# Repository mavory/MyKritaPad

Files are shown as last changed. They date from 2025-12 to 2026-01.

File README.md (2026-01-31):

# MyKritaPad

MyKritaPad is a custom 9-key macropad powered by a Seeed Studio XIAO RP2040!
It includes 9 mechanical switches wired through 9 diodes and two EC11 rotary encoders for additional input control. ⭐



## Why did I do this?

I wanted to try something completely new that I had never done before. I was very interested in how everyone can create their own mini keyboard, so I tried it too.

## Notes

I started on Friday, October 28th. That day I saw that I could make my own mini keyboard, I registered and downloaded the programs. Then I opened KiCad and told myself that I would never do it (it was like flying a plane for the first time). Well, I had to overcome myself and started creating with it. At first it was terrible, but somehow I got over it.

Unfortunately, on October 29th I got sick and couldn't do anything at all, but on November 30th I overcame myself and started creating the first designs for my KritaPad. When I created it with it, I moved to Fusion, which I also looked into, what it was... Somehow I did it, even though I don't want to think about it.

Then on December 1st I overcame myself and spent the whole day at the computer to finish it. In the evening I finished and submitted the project.

## Features
- 9 mechanical keys  
- 9x diodes for proper key isolation  
- 12x SK6812 MINI-E addressable RGB LEDs (RGB LEDs unfortunately I had a bad footprint and because of that my neopixels don't work)  
- 2x EC11 rotary encoders
- Powered by Seeed Studio XIAO RP2040  
- Designed for use with KMK or custom firmware  

## PCB
The PCB is designed in KiCad and includes:
- 9 key switch footprints  
- diode matrix wiring  
- daisy-chained SK6812 MINI-E LEDs 
- pins for two rotary encoders  
- XIAO RP2040 as the main controller  

### Schematic

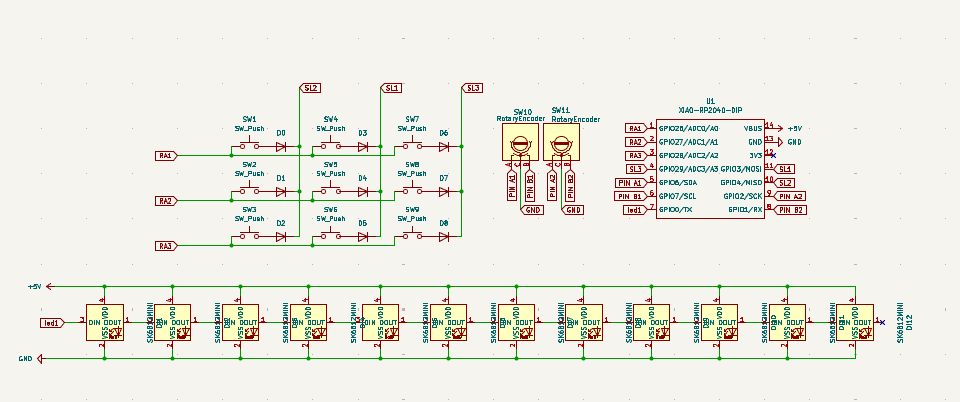
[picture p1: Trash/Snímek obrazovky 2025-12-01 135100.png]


### PCB Layout
(I know, it's terrible.)

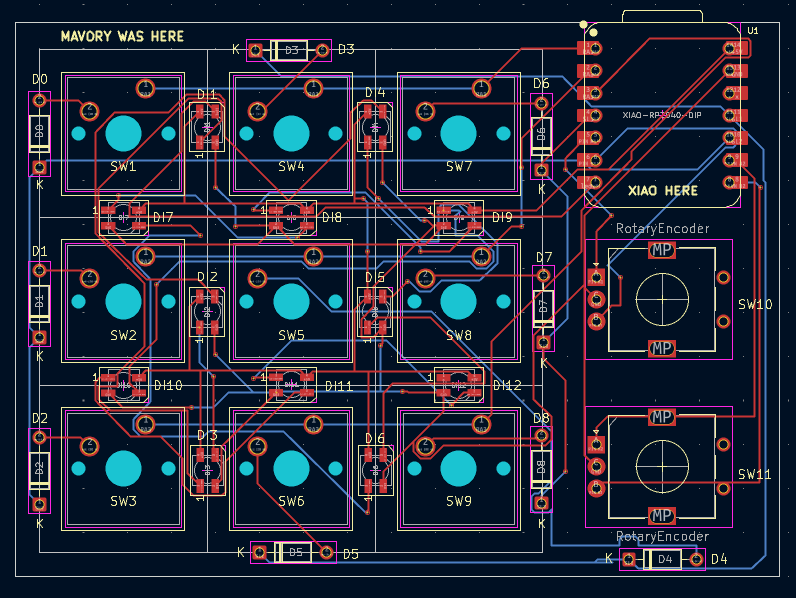
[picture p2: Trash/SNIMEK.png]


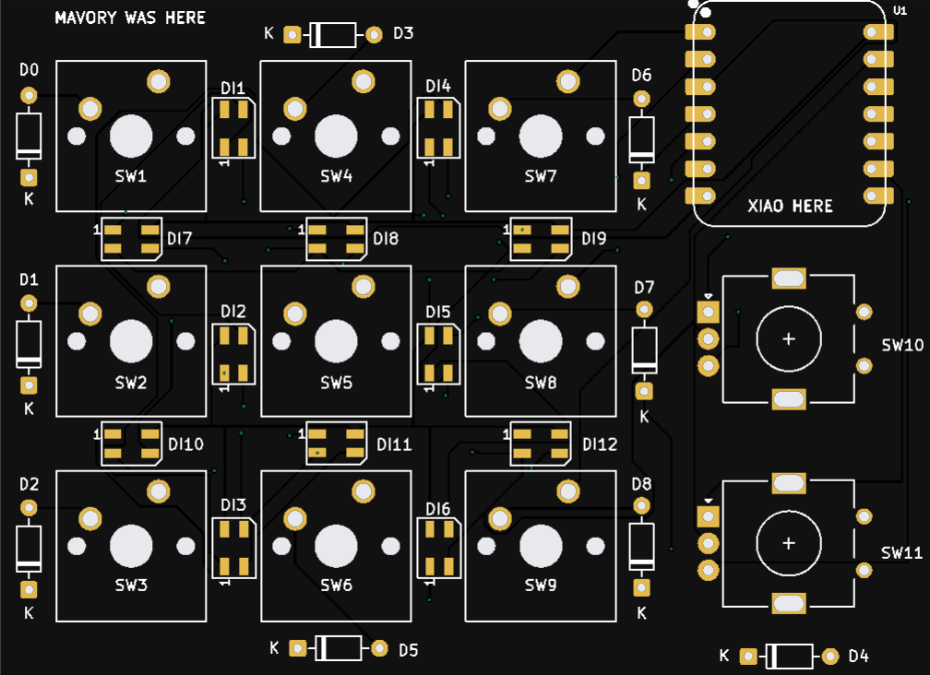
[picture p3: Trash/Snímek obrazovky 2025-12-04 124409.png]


### Top view

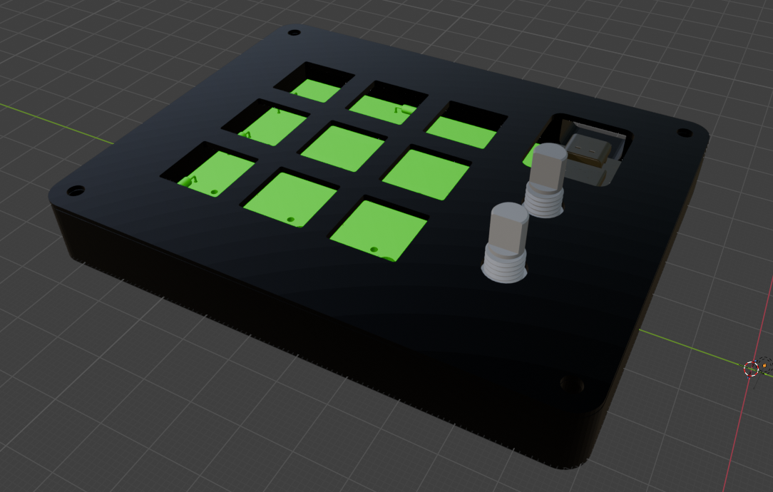
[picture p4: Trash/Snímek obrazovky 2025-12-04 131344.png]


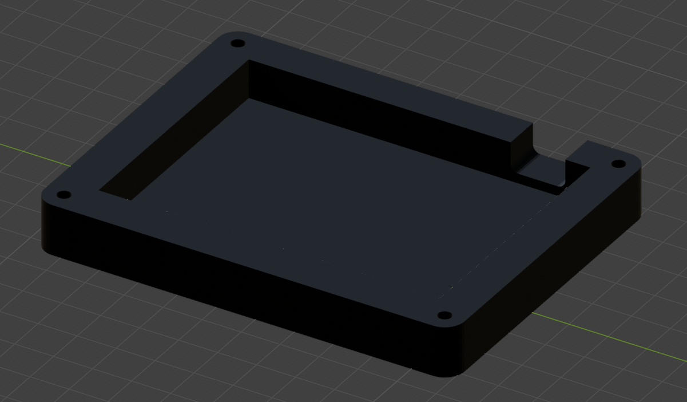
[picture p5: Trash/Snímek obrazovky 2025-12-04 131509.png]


## Firmware
The macropad can be programmed using KMK,... or any custom RP2040 firmware.  

## BOM

### Custom Components
- 1x Custom PCB  
- 1x 3D printed case (top, bottom - Black)
- 9x keycaps  

### COTS Components
- 9x mechanical switches (MX style)  
- 9x Blank DSA keycaps
- 9x 1N4148 diodes  
- 12x SK6812 MINI-E LEDs  
- 2x EC11 rotary encoders  
- 1x Seeed Studio XIAO RP2040    
- 4x M3 x 6mm Screws
- 4x M3x5mx4mm heatset inserts

## Info
This macropad is made as part of the Hack Club Hackpad program! ✨

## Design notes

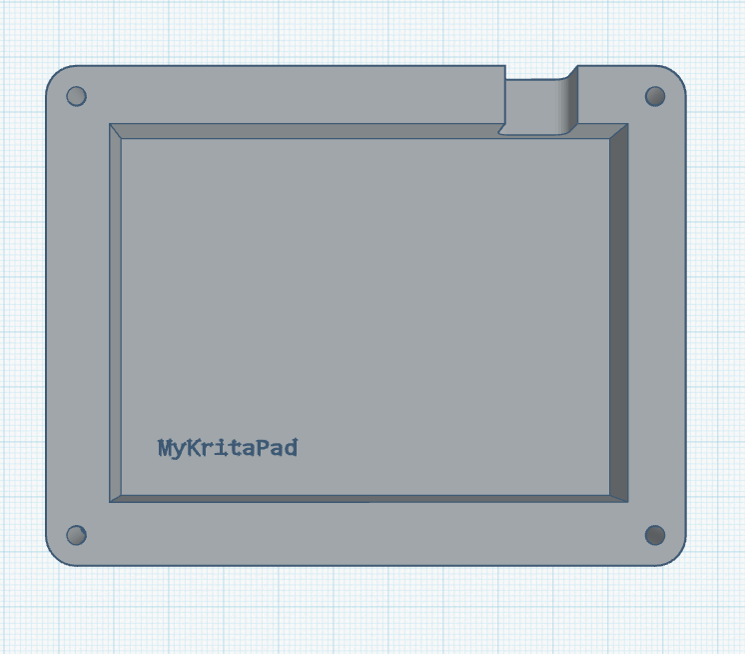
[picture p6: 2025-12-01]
Trash/Snímek obrazovky 2025-12-01 151754.png

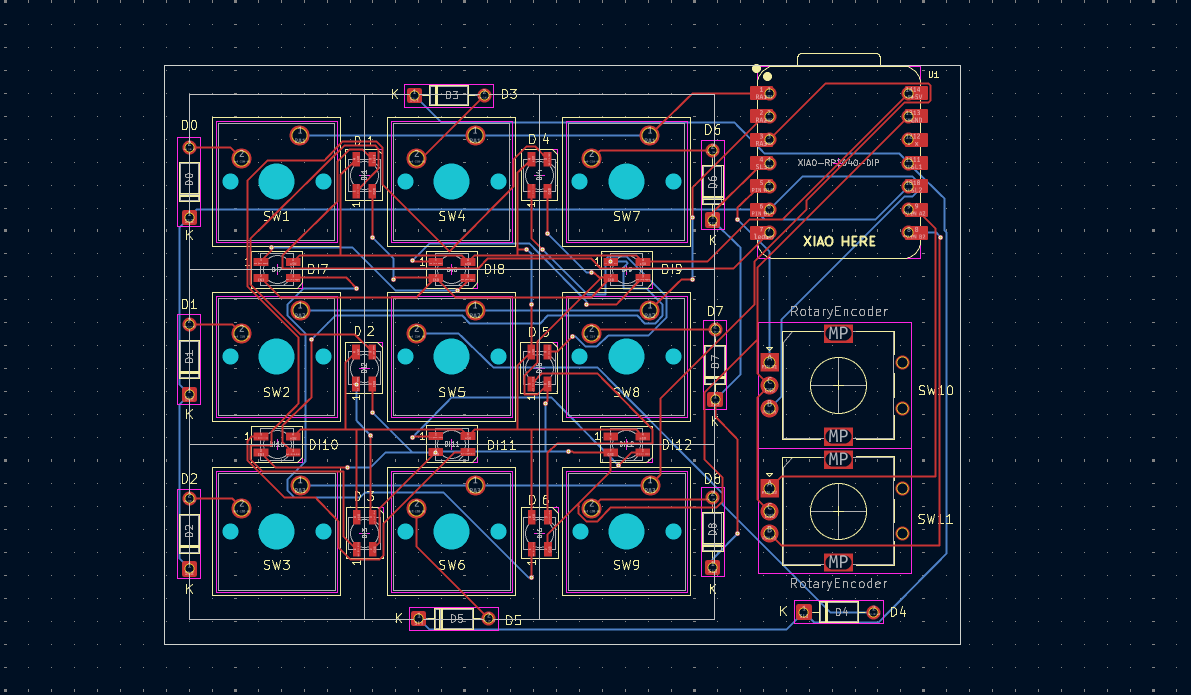
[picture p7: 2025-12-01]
Trash/Snímek obrazovky 2025-12-01 133912.png

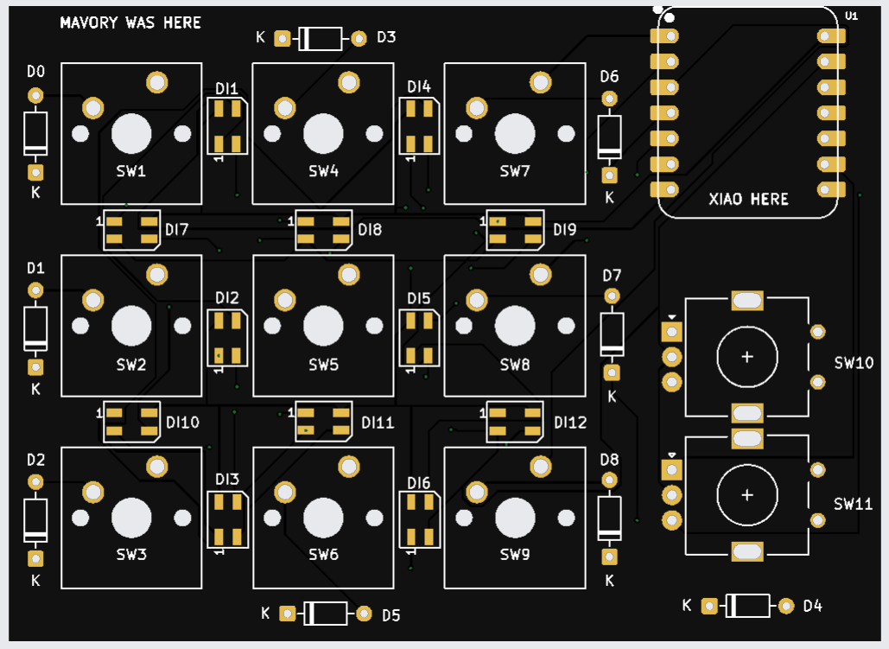
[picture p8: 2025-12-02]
Trash/Snímek obrazovky 2025-12-02 151355.png

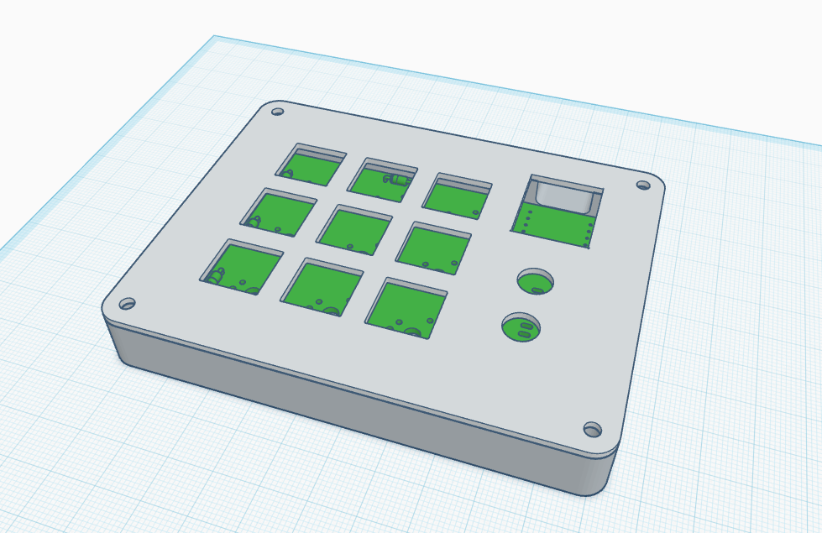
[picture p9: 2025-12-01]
Trash/Snímek obrazovky 2025-12-01 170351.png

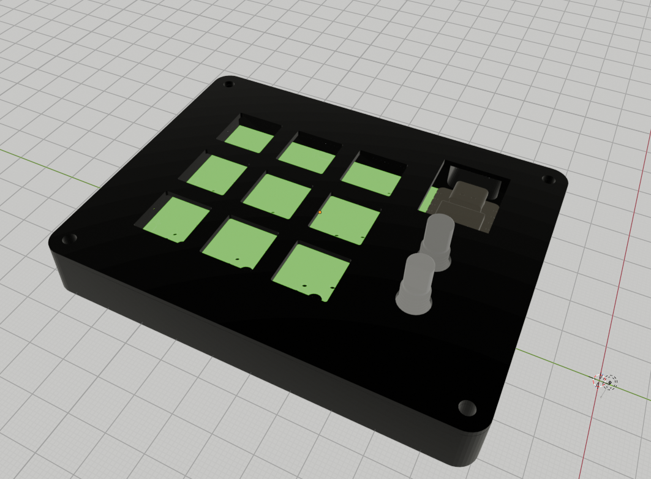
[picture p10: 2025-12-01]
Trash/Snímek obrazovky 2025-12-01 181425.png

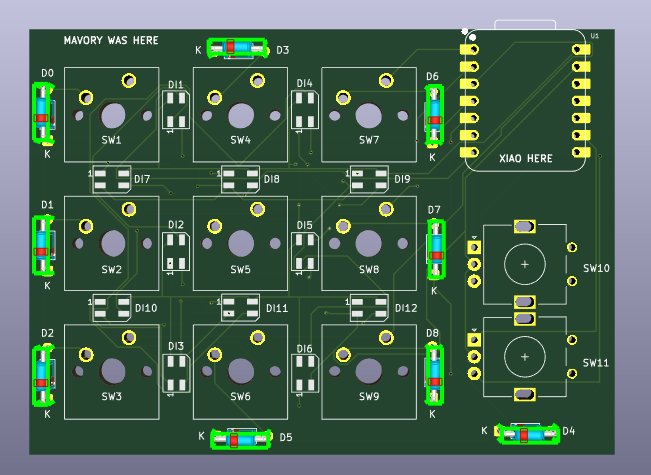
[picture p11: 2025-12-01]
Trash/Snímek obrazovky 2025-12-01 193022.png

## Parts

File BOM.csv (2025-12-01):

Item | Quantity
MX-Style switches | 9
SK6812 MINI-E LEDs | 12
Through-hole 1N4148 Diodes | 9
EC11 Rotary encoders | 2
Seeed XIAO RP2040 | 1
Blank DSA keycaps | 9
3D printed case | 1
M3x16mm screws | 4
M3x5mx4mm heatset inserts | 4

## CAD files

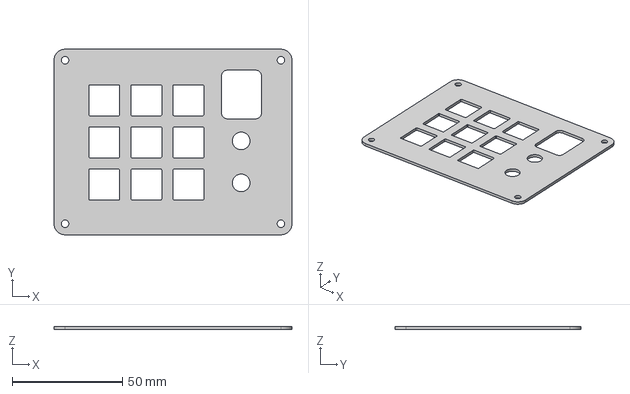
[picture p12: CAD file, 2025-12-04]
CAD/Case-top.step
107.7 x 84.0 x 1.50 mm

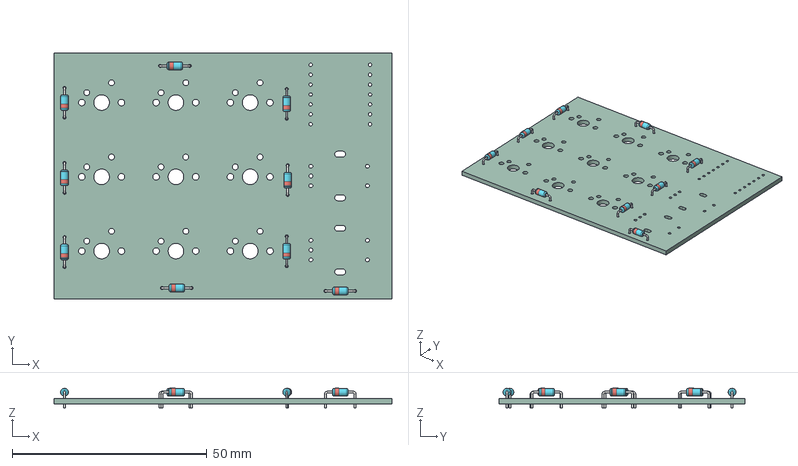
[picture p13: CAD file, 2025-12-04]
PCB/PCB-3D-model.step
86.7 x 63.0 x 5.01 mm
D_DO-35_SOD27_P7.62mm_Horizontal x 9
newmacropad_PCB

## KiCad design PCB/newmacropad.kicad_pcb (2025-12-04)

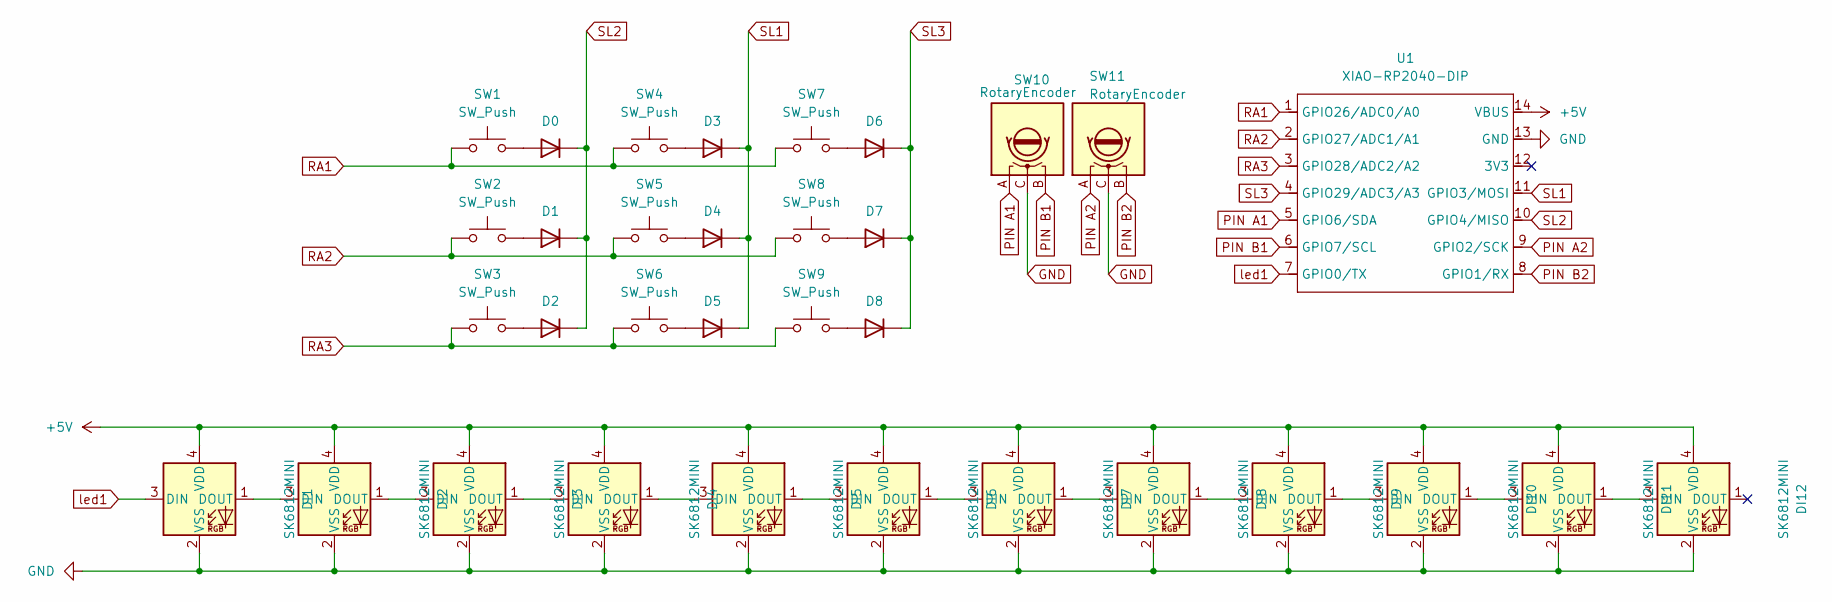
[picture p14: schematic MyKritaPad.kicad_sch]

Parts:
D0, D1, D2, D3, D4, D5, D6, D7, D8: 1N4148; D_DO-35_SOD27_P7.62mm_Horizontal
DI1, DI2, DI3, DI4, DI5, DI6, DI7, DI8, DI9, DI10, DI11, DI12: SK6812MINI; LED_SK6812MINI_PLCC4_3.5x3.5mm_P1.75mm
SW1, SW2, SW3, SW4, SW5, SW6, SW7, SW8, SW9: SW_Push; SW_Cherry_MX_1.00u_PCB
SW10, SW11: RotaryEncoder; RotaryEncoder_Alps_EC11E_Vertical_H20mm
U1: XIAO-RP2040-DIP

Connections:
+5V: DI1.4 (VDD), DI2.4 (VDD), DI3.4 (VDD), DI4.4 (VDD), DI5.4 (VDD), DI6.4 (VDD), DI7.4 (VDD), DI8.4 (VDD), DI9.4 (VDD), DI10.4 (VDD), DI11.4 (VDD), DI12.4 (VDD), U1.14 (VBUS)
GND: DI1.2 (VSS), DI2.2 (VSS), DI3.2 (VSS), DI4.2 (VSS), DI5.2 (VSS), DI6.2 (VSS), DI7.2 (VSS), DI8.2 (VSS), DI9.2 (VSS), DI10.2 (VSS), DI11.2 (VSS), DI12.2 (VSS), SW10.C, SW11.C, U1.13 (GND)
unnamed: D0.2 (A), SW1.2
unnamed: D1.2 (A), SW2.2
unnamed: D2.2 (A), SW3.2
unnamed: D3.2 (A), SW4.2
unnamed: D4.2 (A), SW5.2
unnamed: D5.2 (A), SW6.2
unnamed: D6.2 (A), SW7.2
unnamed: D7.2 (A), SW8.2
unnamed: D8.2 (A), SW9.2
unnamed: DI1.1 (DOUT), DI2.3 (DIN)
unnamed: DI2.1 (DOUT), DI3.3 (DIN)
unnamed: DI3.1 (DOUT), DI4.3 (DIN)
unnamed: DI4.1 (DOUT), DI5.3 (DIN)
unnamed: DI5.1 (DOUT), DI6.3 (DIN)
unnamed: DI6.1 (DOUT), DI7.3 (DIN)
unnamed: DI7.1 (DOUT), DI8.3 (DIN)
unnamed: DI8.1 (DOUT), DI9.3 (DIN)
unnamed: DI9.1 (DOUT), DI10.3 (DIN)
unnamed: DI10.1 (DOUT), DI11.3 (DIN)
unnamed: DI11.1 (DOUT), DI12.3 (DIN)
PIN A1: SW10.A, U1.5 (GPIO6/SDA)
PIN A2: SW11.A, U1.9 (GPIO2/SCK)
PIN B1: SW10.B, U1.6 (GPIO7/SCL)
PIN B2: SW11.B, U1.8 (GPIO1/RX)
RA1: SW1.1, SW4.1, SW7.1, U1.1 (GPIO26/ADC0/A0)
RA2: SW2.1, SW5.1, SW8.1, U1.2 (GPIO27/ADC1/A1)
RA3: SW3.1, SW6.1, SW9.1, U1.3 (GPIO28/ADC2/A2)
SL1: D3.1 (K), D4.1 (K), D5.1 (K), U1.11 (GPIO3/MOSI)
SL2: D0.1 (K), D1.1 (K), D2.1 (K), U1.10 (GPIO4/MISO)
SL3: D6.1 (K), D7.1 (K), D8.1 (K), U1.4 (GPIO29/ADC3/A3)
led1: DI1.3 (DIN), U1.7 (GPIO0/TX)

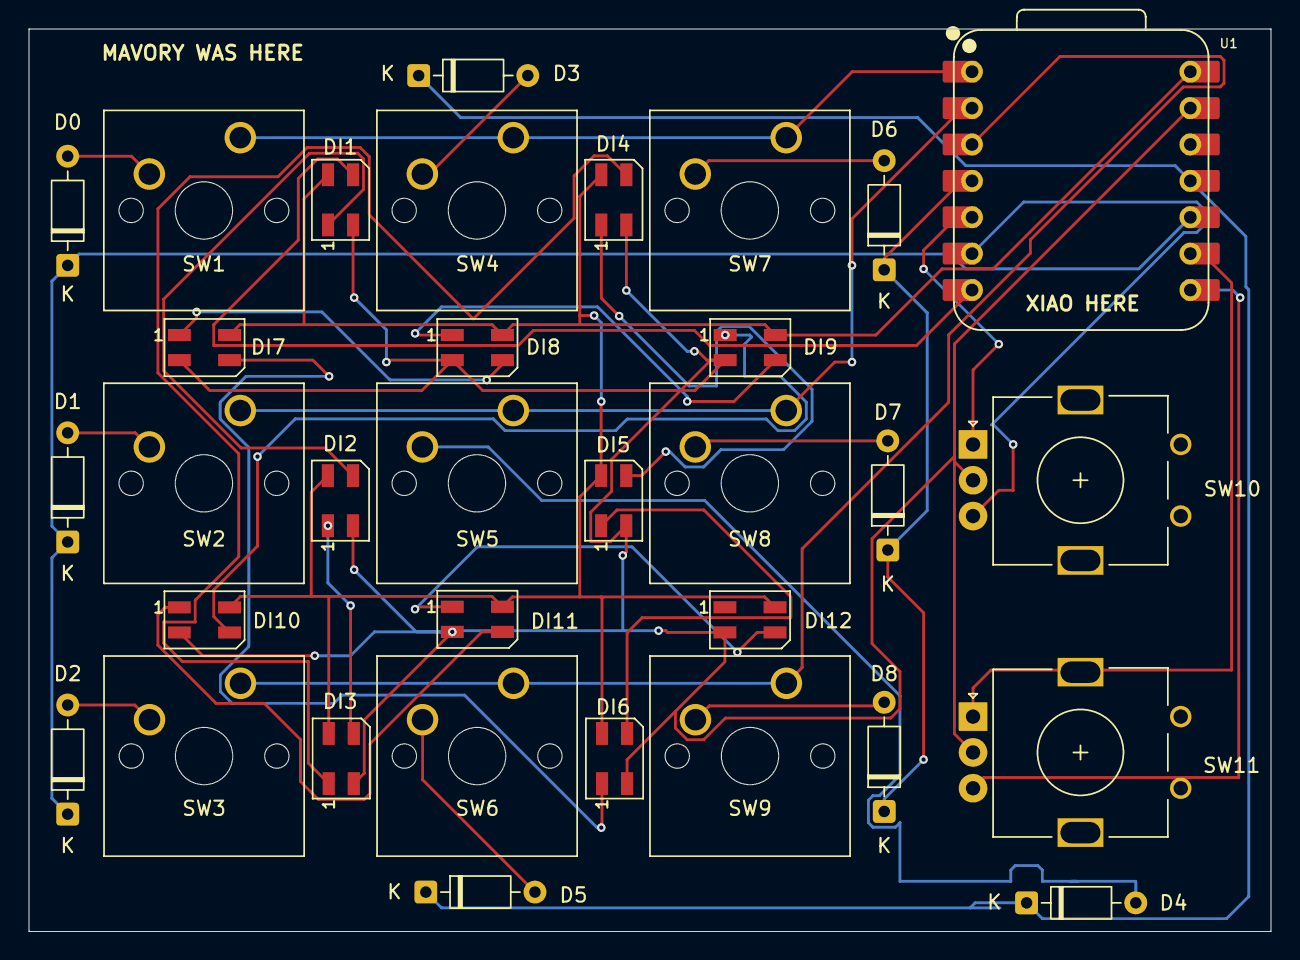
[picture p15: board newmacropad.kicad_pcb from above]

Board: 2 copper layers, 86.7 x 63.0 mm, 33 parts (0 on the bottom side), 33 nets.

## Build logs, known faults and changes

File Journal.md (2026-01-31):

# My Journal

This is my write-up of how I made my first PCB project.

## 12/6/2025 5:08 PM - First Contact with KiCad (Total Panic Mode)  

_Time spent: 2.5h_  

I started on Friday, October 28th. That day I saw that I could make my own mini keyboard, I registered and downloaded the programs. 
Then I opened KiCad and said to myself that I would never do it (it was like flying a plane for the first time). Well, I had to overcome myself and started creating with it. At first it was terrible, but somehow I got through it. I tried to do different options 4x3, 5x3,... I did it all afternoon and then the whole evening. 
At midnight I told myself that I would sleep and continue in the morning.
Snímek obrazovky 2025-11-28 221211

## 12/6/2025 5:12 PM - Redesign PCB  

_Time spent: 2.8h_  

I got up in the morning and started working on the HackPad right away, I told myself that I could create a 3x5 and I started redoing it all. 
It took me the whole morning, but unfortunately I got sick in the afternoon of October 29th and couldn't do anything at all, but on November 30th I got over myself and continued working.
I just fine-tuned the schematic and started making a PCB design. That took me a whole day because I didn't know how to do it. Then I created it and found out that it exceeded 100mmx100mm... So I started over again and worked on it until the evening. Snímek obrazovky 2025-11-29 110834

## 12/6/2025 5:16 PM - Making a 3D case  

_Time spent: 3.1h_  

On the morning of December 1st, I woke up early to finish it. In the morning, I finished the PCB design, which took me about 3 hours. 
Before lunch, I started making a 3D model in Fusion, I didn't know how it worked at all, so I was a little confused. But I started modeling the lower part, which took me a long time. I didn't know how to deal with lengths at all, but I somehow managed it. 
That same day, I made the upper part, but I had more trouble with it. In the evening, I finished the GitHub repo and filmware. Snímek obrazovky 2025-12-01 151754

## 12/6/2025 5:21 PM - Fixing Mistakes  

_Time spent: 2.0h_  

On December 2nd I realized that a few things didn't fit, so I had to redo it a bit... I adjusted the holes for the encoders and also redid the top 3D part. That probably took me over 2 hours of work. Snímek obrazovky 2025-12-04 124409

## 12/6/2025 5:28 PM - Final Exports and First Print  

_Time spent: 1.3h_  

On December 3rd I was finishing and exporting the files I was going to print and also creating a folder for the PCB. It took me about 1 hours in total - because I didn't know how file export works in KiCad at all.
I also had to further edit the 3D models in the slicer to get it right. That same day I printed the bottom case, you can see it here:
bottom

## 12/6/2025 5:35 PM - Continued Printing and New Encoder Knob  

_Time spent: 1.0h_  

On 4. 12. I continued printing and forgot to create a knob for the encoder, so I finished it and printed it. It took me about 1 hour in total.
I was looking for a soldering iron that I could buy from my grand, I found it and bought it too. I then created an order on JLCPCB. I managed to do everything in about an hour.JLCPCB

## 12/6/2025 5:42 PM - Customs Forms and Firmware Update  

_Time spent: 1.0h_  

On December 6, I unexpectedly received an email from our state post office asking me to fill out customs information, it was my first time doing it so I didn't know how to do it, but I managed to do it. I also redid filmware that day so my pad could do more things! I edited the 3D parts and removed the unevenness. I spent about 1 hours on it that day.

## 1/31/2026 10:15 PM - The packages have arrived :)  

_Time spent: 0.3h_  

It took a long time to arrive, but on December 19th I received the package in my hands. I was so excited to build it!
When I got home, I immediately unpacked the package and looked at all the components, then I sorted them according to what I would need and what I didn't...

About a week later the PCB arrived and I quickly ran to the post office to get it and then I just waited for the solder to put it all together.


## 1/31/2026 10:22 PM - Preparing things  

_Time spent: 1.0h_  

When all the things arrived on 29.1., I could start putting everything together!!
First I prepared the components and bent the diodes and prepared the PCB, solder,... But I was thinking about what to start with first and I decided that I would take advantage of the fact that neopixels are so small to start with them! (but I didn't know that it would be such a terrible thing...)

## Big mistake in soldering...

I put flux on the pins and started to apply tin, and after a while I took the first solder and put it there and soldered it. Everything went well, but after a while the solder completely fell apart and I had to replace the entire PCB because the contacts broke off.



## 1/31/2026 10:27 PM - Soldering  

_Time spent: 1.5h_  

I learned from my mistake and moved on, since I had it, I could have continued with more neopixels and then also with diodes, which were well soldered!


Next, I took the buttons and soldered them one by one, I did the same with the encoders, but the tin didn't melt very well, so I had to increase the temperature and then it worked!
As the last one, I soldered the RP2040 and I was slowly done.


## 1/31/2026 10:51 PM - Codinggggg  

_Time spent: 1.2h_  

Before I even put everything in the case, I started coding and thought about how to connect everything.
I decided to use KMK because it seemed like the best and easiest way. At first, I had to study how CircuitPython works with KMK, but it went pretty quickly!
First, I created a code with neopixelelm, which is built-in, to test, see if everything works and works :) Then I continued with the buttons, which took me a long time to get working, because I didn't understand the logic at all...
But after a long time, I had the whole basic thing ready.


## 1/31/2026 10:58 PM - Completing the project!  

_Time spent: 1.0h_  

I immediately started putting everything into the case. At first I had to trim the pins that were sticking out from under the PCB so I could close it all.
Then I took all the components and was able to close the case! I mounted everything, but then I had to do a balance test to make sure everything fit and didn't wobble - so I adjusted the nuts and everything was okay!
I also glued the sides that didn't fit well and would make a bad impression. Then I put on the keycaps and the knob for the encoder, which I decided to print in red for contrast and to break up the whole look.


## 1/31/2026 11 PM - Continuing coding  

_Time spent: 1.3h_  

Even before submitting the project, I said to myself that I had to edit the code to make it really cool!
I started thinking about what functions I could use and decided on layers... I did it so that if I press the bottom button twice, the layers would change.
At first, I couldn't do it at all and the light would always get stuck on one color... I thought I wouldn't be able to solve it, because we sat there for about half an hour, but then I came up with a solution:
- _Don't do it automatically with the layer, but do it manually (so that if I press the button twice, the color and the layer will switch)._

So when I finished this code and mapped all the things, I had to finish a few things on the computer, because some applications were opened, for example, via F15, F14,...
Snímek obrazovky 2026-01-31 230926
  
-----------

## So how much time did I spend on that?

A lot. (Just kidding. like I said, it was my first time doing this, so about  8 days 😭)

## My worst hangups

- I didn't even know how to export anything at all at first...
- MAINLY, how the programs work
- Connecting the PCB so it didn't look like spaghetti (but I still managed to make it)
- The worst part: learning how to operate Fusion (I've never used it and it annoyed me that I couldn't just move the mouse and look at the 3d model, but then I found out that I could 😭)

## Some photos:

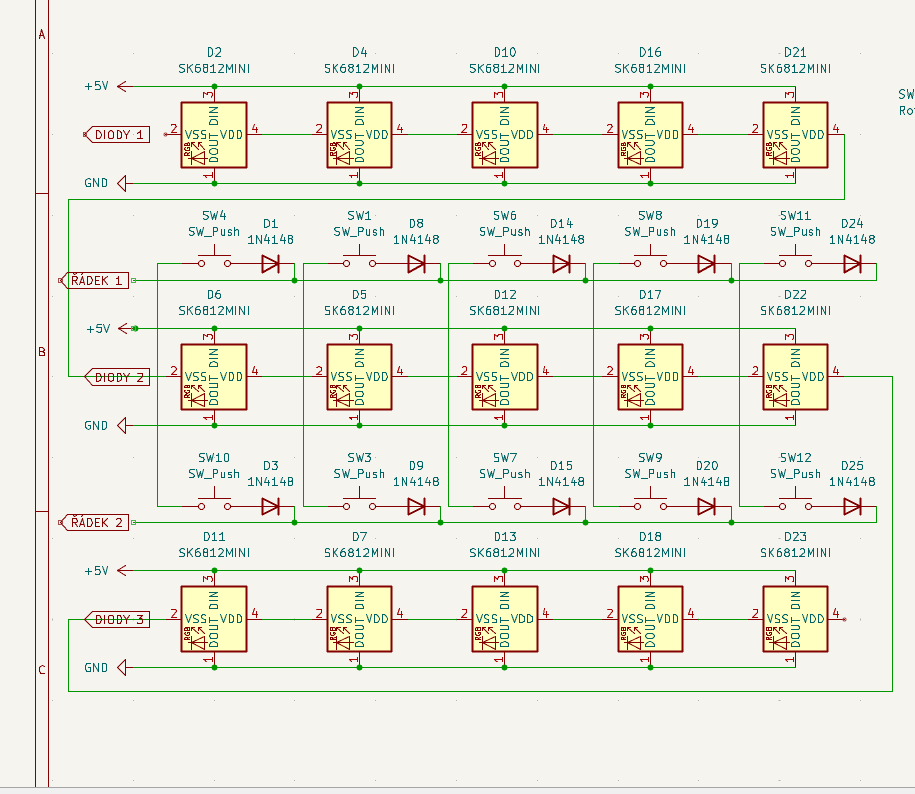
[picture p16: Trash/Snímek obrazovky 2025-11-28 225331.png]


Yes, this is my work... (I didn't even know what I was doing - that's the first day I've done it, so Friday 11/28)

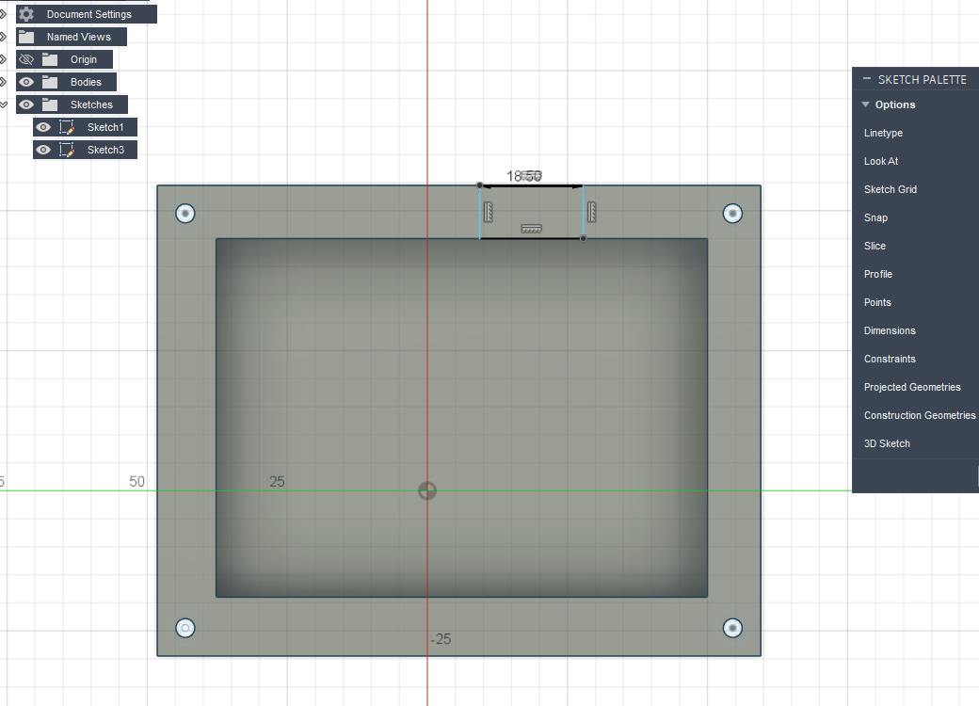
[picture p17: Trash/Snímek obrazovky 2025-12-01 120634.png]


Here I was thinking I would never learn.

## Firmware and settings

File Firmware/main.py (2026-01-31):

import board
import neopixel
import time
from kmk.kmk_keyboard import KMKKeyboard
from kmk.keys import KC
from kmk.scanners import DiodeOrientation
from kmk.modules.encoder import EncoderHandler
from kmk.modules.layers import Layers
from kmk.modules.tapdance import TapDance
from kmk.extensions.media_keys import MediaKeys

keyboard = KMKKeyboard()
keyboard.modules.append(Layers())
keyboard.modules.append(EncoderHandler())
keyboard.modules.append(TapDance())
keyboard.extensions.append(MediaKeys())

# mega tvrdy reset!
pixel = neopixel.NeoPixel(board.NEOPIXEL, 1, brightness=0.3, auto_write=True)

def force_reset_led(color):
    # 1. resetik
    pixel[0] = (0, 0, 0)
    time.sleep(0.01) # pauza, ale jako fakt krátká
    # 2. nova barva
    pixel[0] = color
    pixel.show()

force_reset_led((0, 0, 255)) # blueeee

# tlačitka pro reset,...
class LayerResetKey:
    def __init__(self, layer, color):
        self.layer = layer
        self.color = color

    def on_press(self, keyboard, coord_int=None):
        force_reset_led(self.color)
        return KC.TO(self.layer).on_press(keyboard, coord_int)

    def on_release(self, keyboard, coord_int=None):
        return KC.TO(self.layer).on_release(keyboard, coord_int)

# definice resetovacích věci
GO_L0 = LayerResetKey(0, (0, 0, 255))
GO_L1 = LayerResetKey(1, (255, 0, 0))
GO_L2 = LayerResetKey(2, (0, 255, 0))

# matice
keyboard.row_pins = (board.D0, board.D1, board.D2)
keyboard.col_pins = (board.D9, board.D10, board.D3)
keyboard.diode_orientation = DiodeOrientation.ROW2COL

encoder_handler = keyboard.modules[1]
encoder_handler.pins = ((board.D4, board.D5, None, True), (board.D8, board.D7, None, True))
encoder_handler.divisor = 4
encoder_handler.map = [
    ((KC.AUDIO_VOL_UP, KC.AUDIO_VOL_DOWN), (KC.LCTL(KC.TAB), KC.LCTL(KC.LSFT(KC.TAB)))),
    ((KC.MEDIA_NEXT_TRACK, KC.MEDIA_PREV_TRACK), (KC.MWEL_UP, KC.MWEL_DOWN)),
    ((KC.LCTL(KC.PENT), KC.LCTL(KC.PMNS)), (KC.PGUP, KC.PGDN)),
]

# mapování vrstev přes SW9
keyboard.keymap = [
    [   # modricka barvicka L0
        KC.F14,         KC.F15,         KC.F16,
        KC.LALT(KC.F4), KC.LGUI(KC.L),  KC.LGUI(KC.LSFT(KC.S)),
        KC.LCTL(KC.C),  KC.LCTL(KC.V),  KC.TD(KC.AUDIO_MUTE, GO_L1) 
    ],
    [   # cervena barva L1
        KC.MEDIA_PLAY_PAUSE, KC.CALCULATOR,  KC.LCTL(KC.LSFT(KC.ESC)),
        KC.LGUI(KC.LEFT),    KC.LGUI(KC.UP),  KC.LGUI(KC.RIGHT),
        KC.LCTL(KC.A),       KC.LCTL(KC.X),  KC.TD(KC.AUDIO_MUTE, GO_L2) 
    ],
    [   # zelena barva L2
        KC.F5,               KC.F10,          KC.F11,
        KC.LCTL(KC.F),       KC.LCTL(KC.B),   KC.LCTL(KC.P),
        KC.LCTL(KC.LSFT(KC.K)), KC.LCTL(KC.LSFT(KC.P)), KC.TD(KC.AUDIO_MUTE, GO_L0) 
    ]
]

if __name__ == '__main__':
    keyboard.go()

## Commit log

2025-12-01 Create CAD
2025-12-01 Create PCB
2025-12-01 Add PCB
2025-12-01 Update README with PCB layout note
    Added a note about the PCB layout quality.
2025-12-01 Add schematic image to README
2025-12-01 Add PCB layout image to README
2025-12-01 Update README to simplify rotary encoders description
2025-12-01 Add firmware for 3x3 macropad with RGB effects
    Initial implementation of a 3x3 macropad with encoders and RGB LED effects.
2025-12-01 Add boot.py for KMK/CircuitPython configuration
2025-12-01 Update case color in README
2025-12-01 Don´t look 🧑‍🦽
2025-12-04 3D models
    [Case-top.step]
2026-01-31 Filmware
    Refactor main.py to update encoder handling and RGB setup.
2026-01-31 Scripts
    Refactor keyboard setup and add layer reset functionality.
    [main.py]
2026-01-31 Journal.md
    Updated journal entries with detailed progress on PCB project, including timelines, tasks completed, and time spent on each phase. Added images to illustrate the process.
2026-01-31 README.md
    Removed mention of RGB LEDs not working due to footprint issue.
